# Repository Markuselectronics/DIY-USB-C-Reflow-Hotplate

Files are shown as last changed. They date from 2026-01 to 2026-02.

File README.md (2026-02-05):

# 🔥 DIY USB-C PD Reflow Hotplate

**A professional, pocket-sized soldering hotplate powered by USB-C Power Delivery.**

This repository contains all design files for the project.
👉 **Full Tutorial & Guide:** [Link to your Instructables Page]

## 📂 Repository Structure

* **`/Manufacturing`**: Gerber files for JLCPCB.
  * `HotPlate.zip` (Use SMT Assembly)
  * `Plate` (**Order as Aluminum PCB!**)
* **`/Firmware`**: Source code for the STM32 microcontroller.

## ⚠️ Warning
**Hot Surface!** This device reaches 250°C+. Use with caution.

## 🤝 Credits
Huge thanks to **JLCPCB** for sponsoring the PCBs for this project.

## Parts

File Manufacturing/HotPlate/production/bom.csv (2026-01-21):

Designator | Footprint | Quantity | Value | LCSC Part #
BZ1 | Buzzer_12x9.5RM7.6 | 1 | Buzzer | C96093
C1, C17, C2, C21, C3, C4 | 0805 | 6 | 1uF | C28323
C10, C15 | 0805 | 2 | 47uF | C1745
C11, C13, C14, C18, C22, C5, C8 | 0603 | 7 | 100nF | C1590
C12, C6 | 0805 | 2 | 10uF | C15850
C16 | 0805 | 1 | 10nF | C1710
C19, C20 | 0805 | 2 | 20pF | C1798
C23 | 0603 | 1 | 10pF | C1634
C7 | 0805 | 1 | 6n8 | C1755
C9 | 0603 | 1 | 8n2 | C1322360
D1 | 0805 | 1 | green | C2297
D2, D3 | TVS_ESDA25P35-1U1M | 2 | ESDA25P35-1U1M | C1974707
D4 | SOT-323_SC-70 | 1 | ESDA25W | C2935152
D5, D6 | D_SMA | 2 | SS14 | C2480
D7 | D_SOD-323 | 1 | 1N5819WS | C191023
D8 | 0805 | 1 | yellow | C2296
FB1 | 0603 | 1 | 120R | C14709
J1 | SHOU HAN TYPE-C 16PIN 2MD(073) | 1 | USB-C | C2765186
L1 | L_6.3x6.3_H3 | 1 | 18uH | C168016
Q2 | TO-252-2 | 1 | MDD50N03D
Q4 | SOT-23 | 1 | SS8050 | C2150
Q5, Q6 | SOIC127P600X175-8N | 2 | AO4485 | C51499
R1 | 0805 | 1 | 470R | C17710
R10 | 0805 | 1 | 3k3 | C26010
R11, R14, R17, R18, R19, R22, R3, R9 | 0805 | 8 | 10k | C17414
R12, R13, R20, R21 | 0805 | 4 | 4k7 | C17673
R15 | 0805 | 1 | 270R | C17590
R16 | 0805 | 1 | 3k9 | C17614
R2 | 0805 | 1 | 1k | C17513
R4 | 0805 | 1 | 22k | C17560
R5, R7 | 0805 | 2 | 100k | C149504
R6 | 0805 | 1 | 100R | C17408
R8 | 0805 | 1 | 4k99 | C17677
S1, S3 | SW_TS-1088-AR02016 | 2 | TS-1088-AR02016 | C720477
SW1 | RotaryEncoder_Alps_EC11E-Switch_Vertical_H20mm | 1 | RotaryEncoder | C370970
U1 | LQFP-48_7x7mm_P0.5mm | 1 | STM32F103C8T6 | C8734
U2 | QFN-24-1EP_4x4mm_P0.5mm_EP2.7x2.7mm | 1 | STUSB4500QTR | C2678061
U3 | Texas_R-PDSO-G8_EP2.95x4.9mm_Mask2.4x3.1mm | 1 | TPS54331DR | C9865
U4 | SOIC127P600X175-8N | 1 | MAX6675ISA_ | C16030
X1 | Crystal_SMD_5032-2Pin_5.0x3.2mm | 1 | 8MHz | C115962

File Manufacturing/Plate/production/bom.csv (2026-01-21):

Designator | Footprint | Quantity | Value | LCSC Part #
GND, VDD | TestPoint_THTPad_D3.0mm_Drill1.5mm | 2 | TestPoint

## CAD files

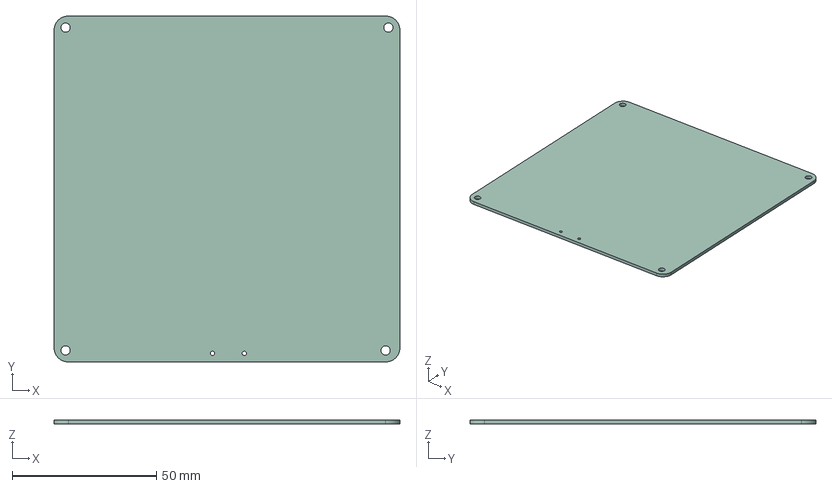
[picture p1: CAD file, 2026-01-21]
Manufacturing/Plate/Plate.step
120.0 x 120.0 x 1.51 mm

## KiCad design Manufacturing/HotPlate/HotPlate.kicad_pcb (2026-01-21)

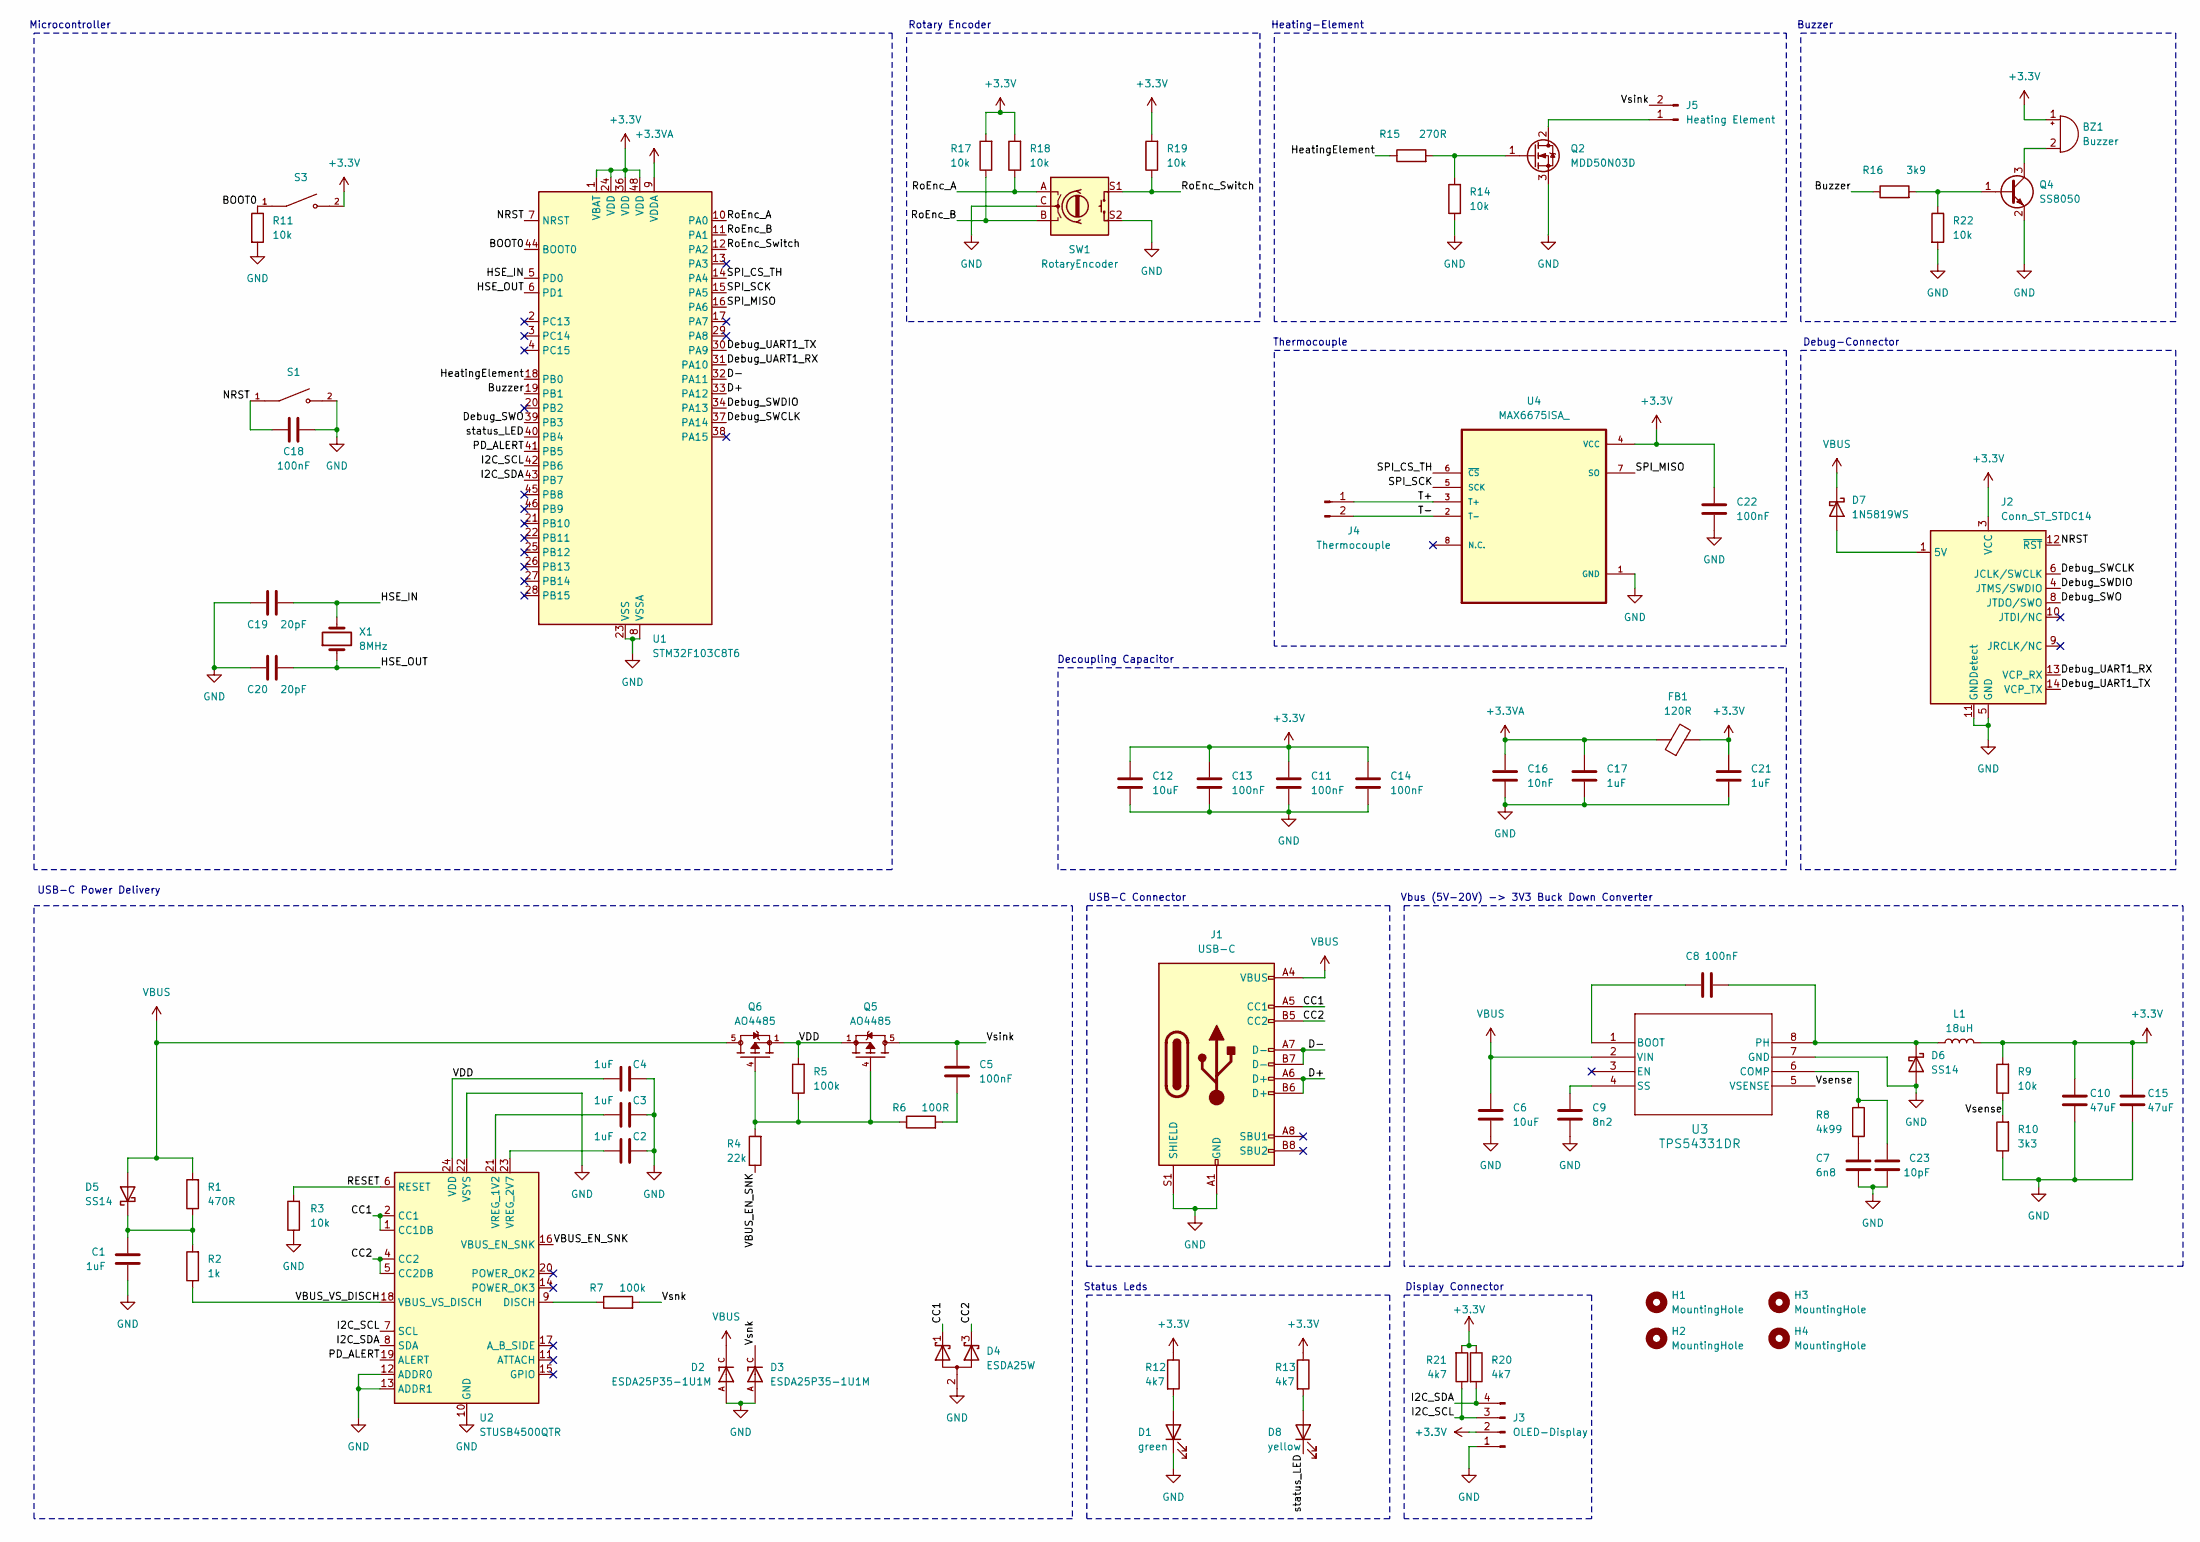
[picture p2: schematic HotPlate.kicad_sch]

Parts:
BZ1: Buzzer; Buzzer_12x9.5RM7.6; LCSC Part # C96093
C1, C2, C3, C4, C17, C21: 1uF; C_0805_2012Metric; LCSC Part # C28323
C5, C8, C11, C13, C14, C18, C22: 100nF; C_0603_1608Metric; LCSC Part # C1590
C6, C12: 10uF; C_0805_2012Metric; LCSC Part # C15850
C7: 6n8; C_0805_2012Metric; LCSC Part # C1755
C9: 8n2; C_0603_1608Metric; LCSC Part # C1322360
C10, C15: 47uF; C_0805_2012Metric; LCSC Part # C1745
C16: 10nF; C_0805_2012Metric; LCSC Part # C1710
C19, C20: 20pF; C_0805_2012Metric; LCSC Part # C1798
C23: 10pF; C_0603_1608Metric; LCSC Part # C1634
D1: green; D_0805_2012Metric; LCSC Part # C2297
D2, D3: ESDA25P35-1U1M; TVS_ESDA25P35-1U1M; PARTREV 2; LCSC Part # C1974707
D4: ESDA25W; SOT-323_SC-70; LCSC Part # C2935152
D5, D6: SS14; D_SMA; LCSC Part # C2480
D7: 1N5819WS; D_SOD-323; LCSC Part # C191023
D8: yellow; D_0805_2012Metric; LCSC Part # C2296
FB1: 120R; R_0603_1608Metric; LCSC Part # C14709
H1, H2, H3, H4: MountingHole; MountingHole_3.2mm_M3
J1: USB-C; SHOU HAN TYPE-C 16PIN 2MD(073); LCSC Part # C2765186
J2: Conn_ST_STDC14; PinHeader_2x07_P1.27mm_Vertical
J3: OLED-Display; PinHeader_1x04_P2.54mm_Vertical
J4: Thermocouple; PinHeader_1x02_P2.54mm_Vertical
J5: Heating Element; PinHeader_1x02_P2.54mm_Vertical
L1: 18uH; L_6.3x6.3_H3; LCSC Part # C168016
Q2: MDD50N03D; TO-252-2
Q4: SS8050; SOT-23; LCSC Part # C2150
Q5, Q6: AO4485; SOIC127P600X175-8N; LCSC Part # C51499
R1: 470R; R_0805_2012Metric; LCSC Part # C17710
R2: 1k; R_0805_2012Metric; LCSC Part # C17513
R3, R9, R11, R14, R17, R18, R19, R22: 10k; R_0805_2012Metric; LCSC Part # C17414
R4: 22k; R_0805_2012Metric; LCSC Part # C17560
R5, R7: 100k; R_0805_2012Metric; LCSC Part # C149504
R6: 100R; R_0805_2012Metric; LCSC Part # C17408
R8: 4k99; R_0805_2012Metric; LCSC Part # C17677
R10: 3k3; R_0805_2012Metric; LCSC Part # C26010
R12, R13, R20, R21: 4k7; R_0805_2012Metric; LCSC Part # C17673
R15: 270R; R_0805_2012Metric; LCSC Part # C17590
R16: 3k9; R_0805_2012Metric; LCSC Part # C17614
S1, S3: TS-1088-AR02016; SW_TS-1088-AR02016; PARTREV N/A; LCSC Part # C720477
SW1: RotaryEncoder; RotaryEncoder_Alps_EC11E-Switch_Vertical_H20mm; LCSC Part # C370970
U1: STM32F103C8T6; LQFP-48_7x7mm_P0.5mm; LCSC Part # C8734
U2: STUSB4500QTR; QFN-24-1EP_4x4mm_P0.5mm_EP2.7x2.7mm; LCSC Part # C2678061
U3: TPS54331DR; Texas_R-PDSO-G8_EP2.95x4.9mm_Mask2.4x3.1mm; LCSC Part # C9865
U4: MAX6675ISA_; SOIC127P600X175-8N; LCSC Part # C16030
X1: 8MHz; Crystal_SMD_5032-2Pin_5.0x3.2mm; LCSC Part # C115962

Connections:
+3.3V: BZ1.1 (+), C10.1, C11.1, C12.1, C13.1, C14.1, C15.1, C21.1, C22.1, FB1.2, J2.3 (VCC), J3.2, L1.2, R9.2, R12.1, R13.1, R17.2, R18.2, R19.2, R20.1, R21.2, S3.2, U1.1 (VBAT), U1.24 (VDD), U1.36 (VDD), U1.48 (VDD), U4.4 (VCC)
+3.3VA: C16.1, C17.1, FB1.1, U1.9 (VDDA)
/BOOT0: R11.1, S3.1, U1.44 (BOOT0)
/Buzzer: R16.1, U1.19 (PB1)
/CC1: D4.1 (K), J1.A5 (CC1), U2.1 (CC1DB), U2.2 (CC1)
/CC2: D4.3 (K), J1.B5 (CC2), U2.4 (CC2), U2.5 (CC2DB)
/D+: J1.A6 (D+), J1.B6 (D+), U1.33 (PA12)
/D-: J1.A7 (D-), J1.B7 (D-), U1.32 (PA11)
/Debug_SWCLK: J2.6 (JCLK/SWCLK), U1.37 (PA14)
/Debug_SWDIO: J2.4 (JTMS/SWDIO), U1.34 (PA13)
/Debug_SWO: J2.8 (JTDO/SWO), U1.39 (PB3)
/Debug_UART1_RX: J2.13 (VCP_RX), U1.31 (PA10)
/Debug_UART1_TX: J2.14 (VCP_TX), U1.30 (PA9)
/HSE_IN: C19.2, U1.5 (PD0), X1.2
/HSE_OUT: C20.2, U1.6 (PD1), X1.1
/HeatingElement: R15.1, U1.18 (PB0)
/I2C_SCL: J3.3, R21.1, U1.42 (PB6), U2.7 (SCL)
/I2C_SDA: J3.4, R20.2, U1.43 (PB7), U2.8 (SDA)
/NRST: C18.1, J2.12 (~RST), S1.1, U1.7 (NRST)
/PD_ALERT: U1.41 (PB5), U2.19 (ALERT)
/RESET: R3.2, U2.6 (RESET)
/RoEnc_A: R18.1, SW1.A, U1.10 (PA0)
/RoEnc_B: R17.1, SW1.B, U1.11 (PA1)
/RoEnc_Switch: R19.1, SW1.S1, U1.12 (PA2)
/SPI_CS_TH: U1.14 (PA4), U4.6 (~CS)
/SPI_MISO: U1.16 (PA6), U4.7 (SO)
/SPI_SCK: U1.15 (PA5), U4.5 (SCK)
/T+: J4.1, U4.3 (T+)
/T-: J4.2, U4.2 (T-)
/VBUS_EN_SNK: R4.1, U2.16 (VBUS_EN_SNK)
/VBUS_VS_DISCH: R2.1, U2.18 (VBUS_VS_DISCH)
/VDD: C4.2, Q5.1, Q5.2, Q5.3, Q6.1, Q6.2, Q6.3, R5.2, U2.24 (VDD)
/Vsense: R9.1, R10.2, U3.5 (VSENSE)
/Vsink: C5.1, J5.2, Q5.5, Q5.6, Q5.7, Q5.8
/Vsnk: D3.C, R7.2
/status_LED: D8.1 (K), U1.40 (PB4)
GND: C1.2, C2.1, C3.1, C4.1, C6.2, C7.2, C9.2, C10.2, C11.2, C12.2, C13.2, C14.2, C15.2, C16.2, C17.2, C18.2, C19.1, C20.1, C21.2, C22.2, C23.1, D1.1 (K), D2.A, D3.A, D4.2 (A), D6.2 (A), J1.A1 (GND), J1.A12 (GND), J1.B1 (GND), J1.B12 (GND), J1.S1 (SHIELD), J2.5 (GND), J2.7 (GND), J2.11 (GNDDetect), J3.1, Q2.3 (S), Q4.2 (E), R3.1, R10.1, R11.2, R14.1, R22.2, S1.2, SW1.C, SW1.S2, U1.8 (VSSA), U1.23 (VSS), U1.35 (VSS), U1.47 (VSS), U2.10 (GND), U2.12 (ADDR0), U2.13 (ADDR1), U2.22 (VSYS), U2.25 (GND), U3.7 (GND), U4.1 (GND)
unnamed: BZ1.2 (-), Q4.3 (C)
unnamed: C5.2, R6.2
unnamed: C7.1, R8.2
unnamed: D1.2 (A), R12.2
unnamed: C1.1, D5.1 (K), R1.1, R2.2
unnamed: C8.2, D6.1 (K), L1.1, U3.8 (PH)
unnamed: D7.2 (A), J2.1 (5V)
unnamed: D8.2 (A), R13.2
unnamed: J5.1, Q2.2 (D)
unnamed: Q2.1 (G), R14.2, R15.2
unnamed: Q4.1 (B), R16.2, R22.1
unnamed: Q5.4, Q6.4, R4.2, R5.1, R6.1
unnamed: R7.1, U2.9 (DISCH)
unnamed: C3.2, U2.21 (VREG_1V2)
unnamed: C2.2, U2.23 (VREG_2V7)
unnamed: C8.1, U3.1 (BOOT)
unnamed: C23.2, R8.1, U3.6 (COMP)
unnamed: C9.1, U3.4 (SS)
VBUS: C6.1, D2.C, D5.2 (A), D7.1 (K), J1.A4 (VBUS), J1.A9 (VBUS), J1.B4 (VBUS), J1.B9 (VBUS), Q6.5, Q6.6, Q6.7, Q6.8, R1.2, U3.2 (VIN)

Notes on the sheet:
USB-C Power Delivery
USB-C Connector
Thermocouple
Debug-Connector
Display Connector
Vbus (5V-20V) -> 3V3 Buck Down Converter
Heating-Element
Rotary Encoder
Microcontroller
Buzzer
Decoupling Capacitor
Status Leds

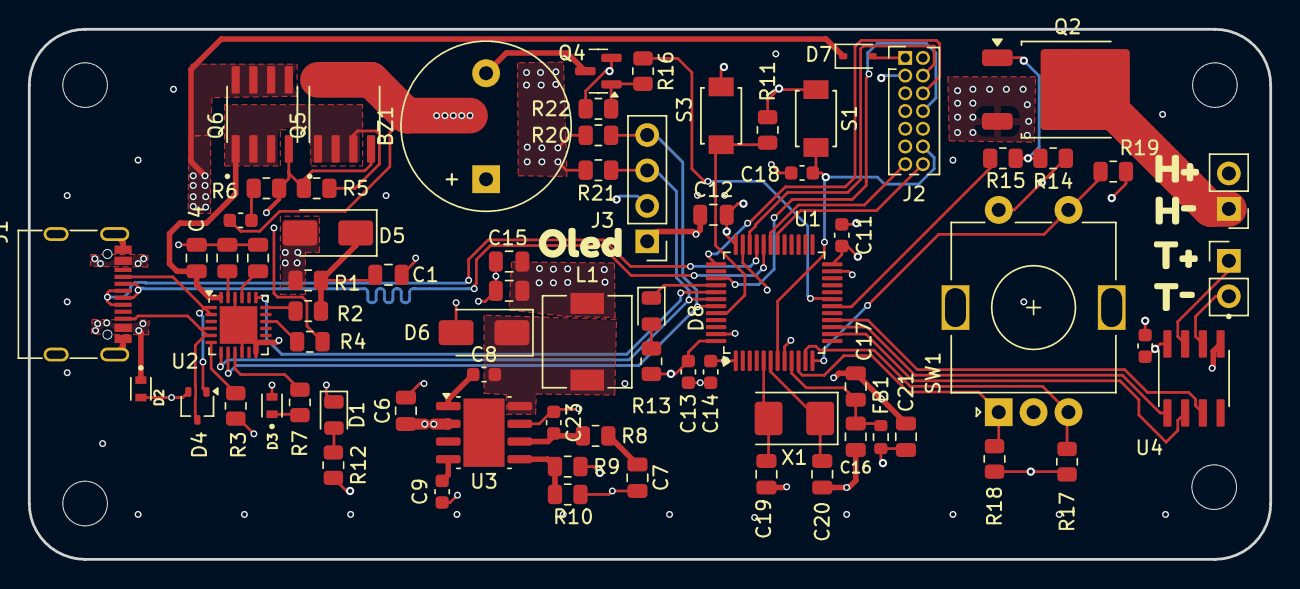
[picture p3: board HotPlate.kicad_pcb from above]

Board: 4 copper layers, 89.0 x 38.0 mm, 82 parts (0 on the bottom side), 56 nets.

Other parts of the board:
kibuzzard-6914F22F: G***; kibuzzard-6914F22F
kibuzzard-6914F142: G***; kibuzzard-6914F142
kibuzzard-6914F203: G***; kibuzzard-6914F203
kibuzzard-6914F211: G***; kibuzzard-6914F211
kibuzzard-6914F240: G***; kibuzzard-6914F240

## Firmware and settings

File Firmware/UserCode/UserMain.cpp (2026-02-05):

#include "UserMain.h"
#include "USB_PD_Handler.h"
#include "i2c.h"
#include "HotPlate.h"
#include "SI_Units.h"

//#include "MenuContent.h"


void setup(){

	// NOTE: This logic executes every time the timer overflows (interrupt context).
	htim4.PeriodElapsedCallback = [] (TIM_HandleTypeDef *htim){Task_1(1*ms);};
	HAL_TIM_Base_Start_IT(&htim4);
	HAL_TIM_Encoder_Start(&htim2, TIM_CHANNEL_ALL);

}

// Periodic task called by the Timer ISR
// param dt: Delta time in seconds since the last call (for integral/derivative calculations)

void Task_1(float dt){
	
	HotPlate(dt);

}

void loop(){
	
updateDisplay();
	
}
	

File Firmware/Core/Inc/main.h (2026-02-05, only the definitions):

#define button_notPressed_Pin GPIO_PIN_2
#define button_notPressed_GPIO_Port GPIOA
#define SPI1_CS_TH_Pin GPIO_PIN_4
#define SPI1_CS_TH_GPIO_Port GPIOA
#define HeatingPlate_on_Pin GPIO_PIN_0
#define HeatingPlate_on_GPIO_Port GPIOB
#define Buzzer_beep_Pin GPIO_PIN_1
#define Buzzer_beep_GPIO_Port GPIOB
#define status_LED_activeLow_Pin GPIO_PIN_4
#define status_LED_activeLow_GPIO_Port GPIOB

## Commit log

2026-02-05 Remove 3D Print section from README
    Removed 3D Print section from README.
2026-02-05 Update HotPlate
    [HotPlate.csv, HotPlate.kicad_pcb, HotPlate.kicad_sch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]

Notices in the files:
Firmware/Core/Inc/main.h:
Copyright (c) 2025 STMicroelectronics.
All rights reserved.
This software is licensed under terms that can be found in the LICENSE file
